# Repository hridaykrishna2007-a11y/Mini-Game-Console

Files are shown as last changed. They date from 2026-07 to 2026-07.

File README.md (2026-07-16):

# Mini-Game-Console
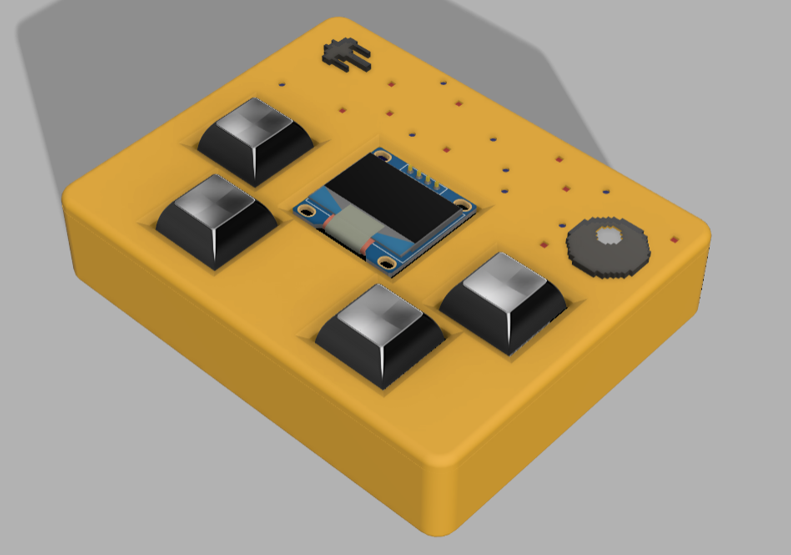
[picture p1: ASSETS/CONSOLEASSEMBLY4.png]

## ***Small handheld game console, it runs on an arduino nano!***
This small DIY console is designed to make teens learn how to build real hardware projects, play games and teach them how to code.  
It runs on an arduino nano and takes power from a usb power source. It has 4 Mechanical CherryMX keyboard switches as the controller buttons. and a 128x64 OLED display!  

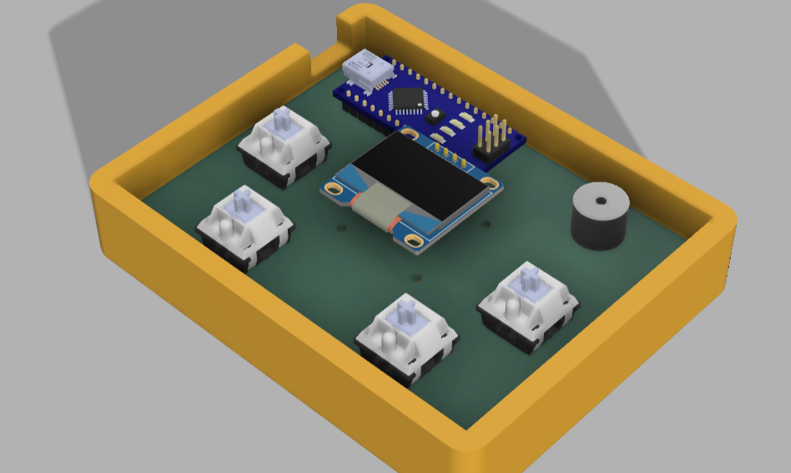
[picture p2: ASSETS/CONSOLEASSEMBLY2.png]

## ***PCB Design & Assembly***
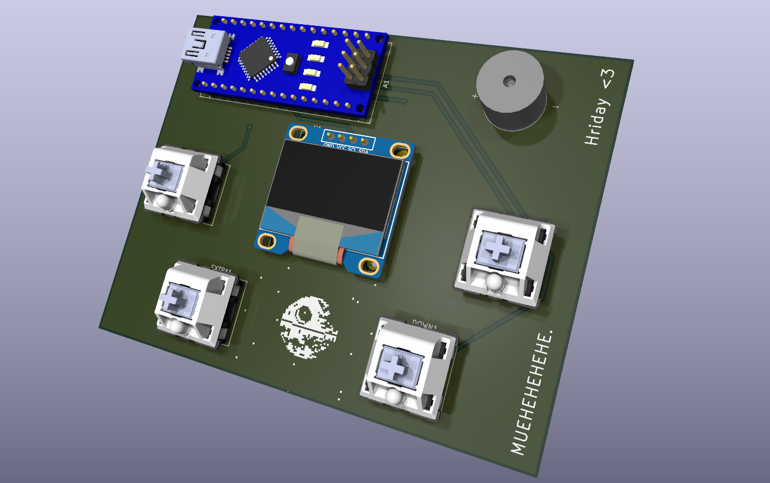
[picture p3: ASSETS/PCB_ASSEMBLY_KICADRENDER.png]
  

This is a 2 layer PCB with dimentions of 99.40x77.02 mm.  

**PCB FILES HERE:** [Link](https://github.com/hridaykrishna2007-a11y/Mini-Game-Console/tree/main/PCB)

## ***Schematics***  
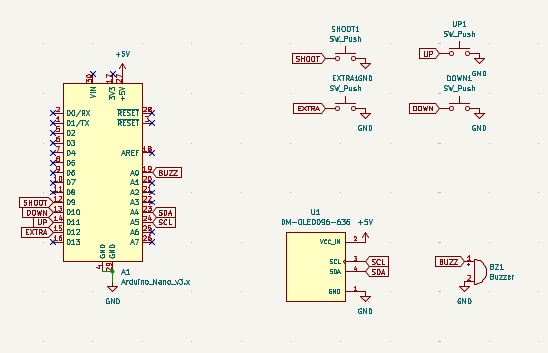
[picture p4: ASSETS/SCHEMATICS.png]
  

## ***PCB Design***
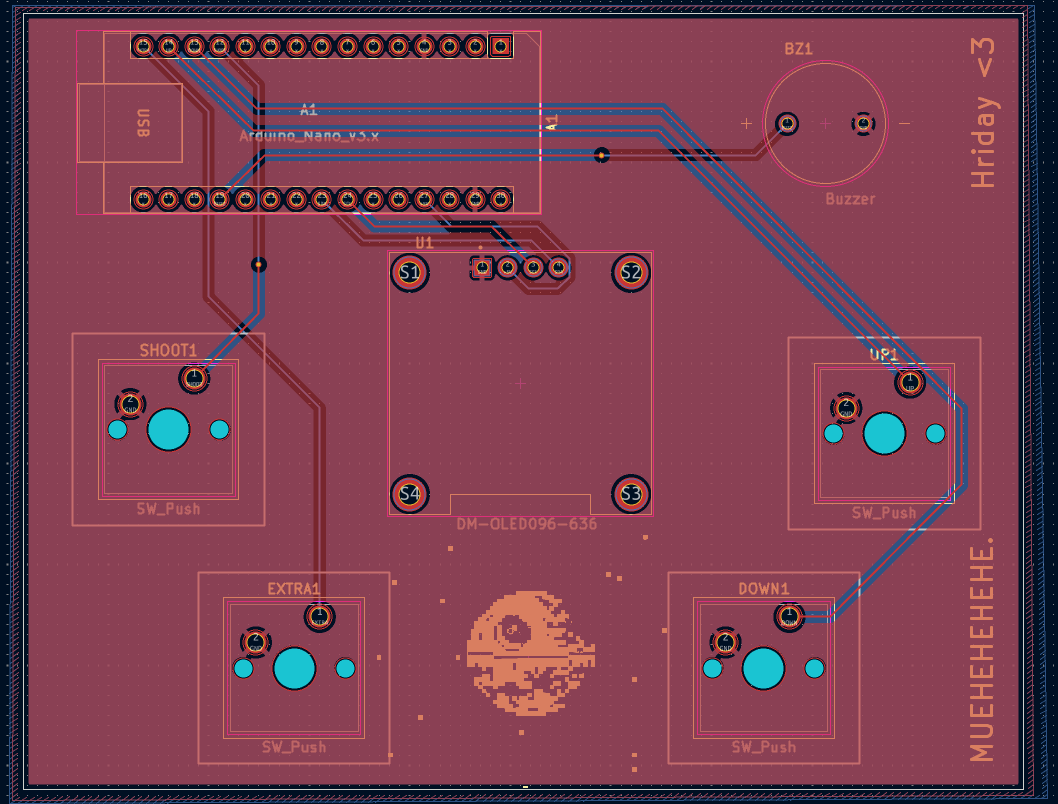
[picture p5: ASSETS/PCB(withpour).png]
  

## Why it was made?
This Project was made for Horizons arcana in singapore ! ( THANK YOU HACK CLUB <3 )

## HOW TO BUILD THIS PROJECT:  
Easy Peasy.
- Order the parts from the BOM and get the case and the keycaps 3d printed and ready.
- Solder the parts on the pcb and keep the orientations in mind (or you are cooked).
- Superglue the case together. (This project is designed keeping portablity and light weight in mind. Hence no screws as it will increase the weight)
- Purchase or 3d print some keycaps (here's one: https://www.printables.com/model/118708-simple-cherry-mx-keycap)
- upload your code (or the sample one in this same repo) using usb cable and arduino ide.
- connec to a power source like a powerbank.
- PLAYYYYYYYY!!!!!!

https://github.com/user-attachments/assets/bd86371d-4319-4f34-b711-88d048939bdb

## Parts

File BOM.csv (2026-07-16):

PRODUCT | DESCRIPTION | QUANTITY | UNIT PRICE | TOTAL COST (INCL. SHIPPING) | LINK
PCB | console pcb | 5 [moq] | 315 | 1861
Arduino nano | Arduino nano microcontroller | 1 | 200 | 200 | https://robocraze.com/products/nano-development-board-compatible-with-arduino
Cable | mini usb cable for the arduino nano | 1 | 39 | 39 | https://robocraze.com/products/mini-usb-cable-0-5-metre-color-may-vary
oled 128x64 | SSD1306 I2C OLED | 1 | 162 | 162 | https://robocraze.com/products/0-96in-oled-display-module-4pin
buzzer | buzzer | 1 | 14 | 14 | https://robocraze.com/products/3-volts-buzzer-small
mechanical switches | swicthes for the keys of the controller | 10 (moq) | 180 | 180 | https://stackskb.com/store/click-inc-hp-switch-pack-of-10-pre-order/
keycaps | keycaps | 4 |  |  | Self Sourced (3D-Printed)
case | case of the pcb | 1 |  |  | Self Sourced (3D-Printed)

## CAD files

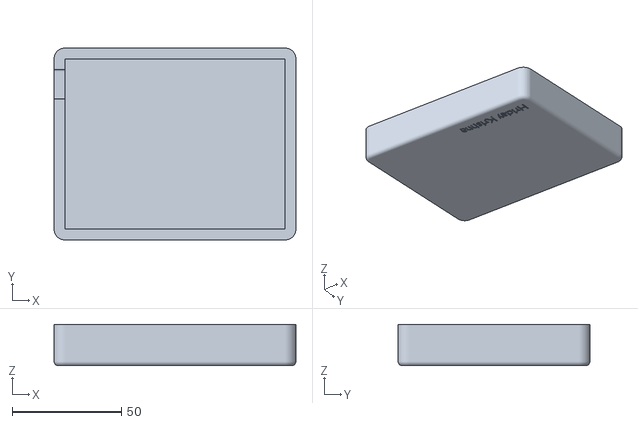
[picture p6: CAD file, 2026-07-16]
PRODUCTION/ENCLOSURE/Case_bottom.stl
111.0 x 88.0 x 19.0

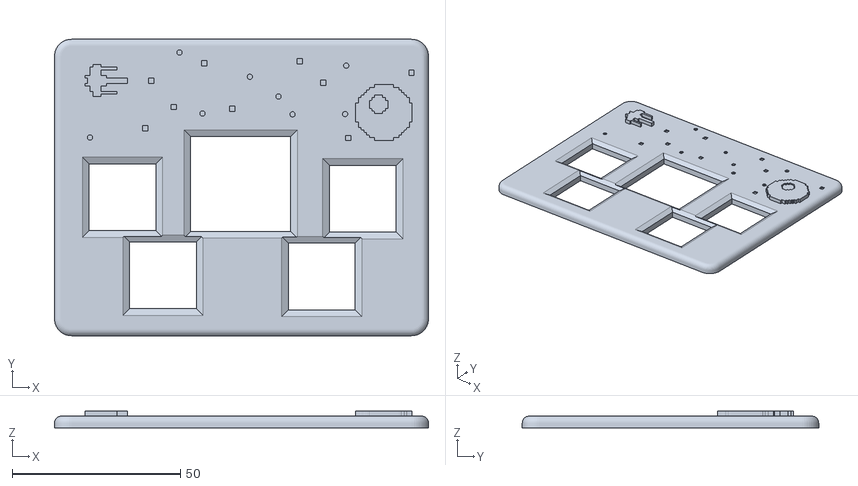
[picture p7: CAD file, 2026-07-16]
PRODUCTION/ENCLOSURE/Case_top.stl
111.0 x 88.0 x 5.00

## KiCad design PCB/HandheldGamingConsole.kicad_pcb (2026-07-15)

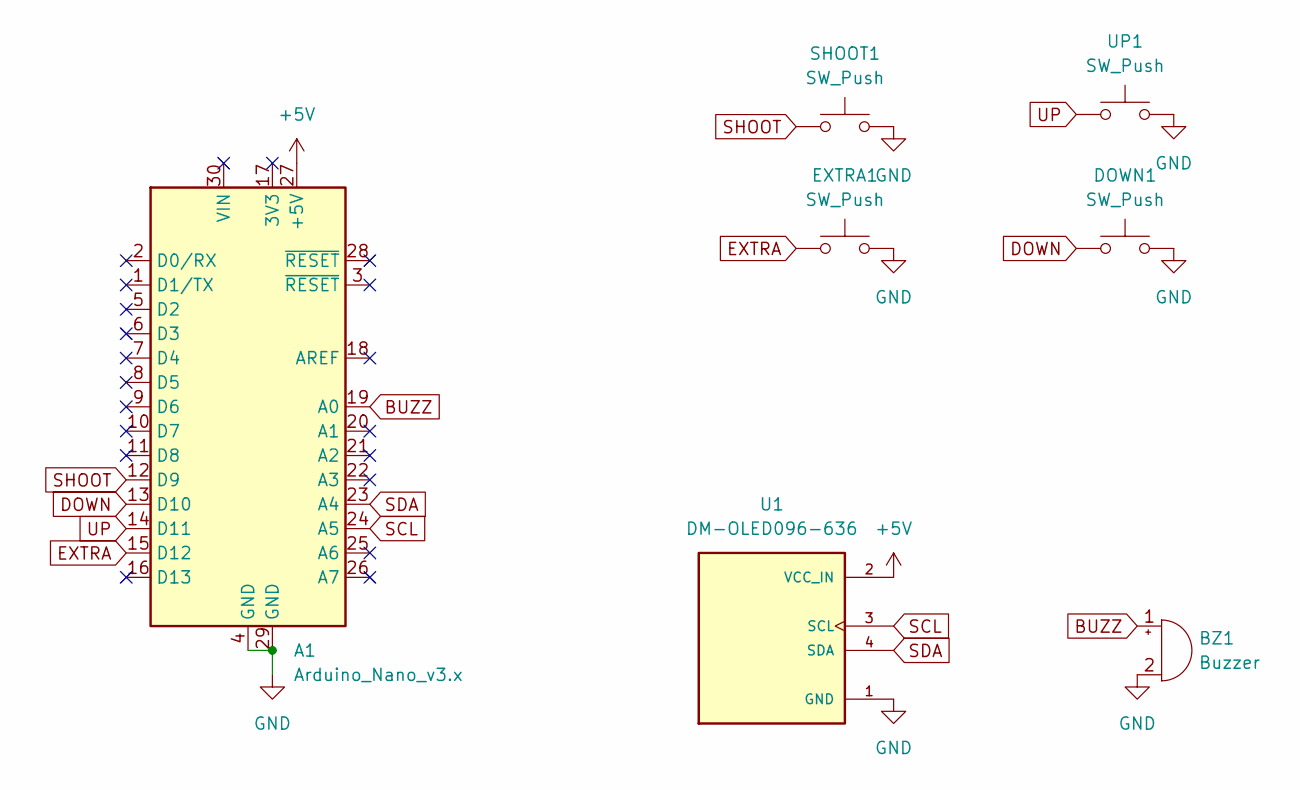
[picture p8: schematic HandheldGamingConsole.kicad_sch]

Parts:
A1: Arduino_Nano_v3.x; Arduino_Nano
BZ1: Buzzer; XDCR_KXG1203C
DOWN1: SW_Push; SW_Cherry_MX_1.00u_PCB
EXTRA1: SW_Push; SW_Cherry_MX_1.00u_PCB
SHOOT1: SW_Push; SW_Cherry_MX_1.00u_PCB
U1: DM-OLED096-636; MODULE_DM-OLED096-636; PARTREV 2018-09-10
UP1: SW_Push; SW_Cherry_MX_1.00u_PCB

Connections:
+5V: A1.27 (+5V), U1.2 (VCC_IN)
BUZZ: A1.19 (A0), BZ1.1 (+)
DOWN: A1.13 (D10), DOWN1.1
EXTRA: A1.15 (D12), EXTRA1.1
GND: A1.4 (GND), A1.29 (GND), BZ1.2 (-), DOWN1.2, EXTRA1.2, SHOOT1.2, U1.1 (GND), UP1.2
SCL: A1.24 (A5), U1.3 (SCL)
SDA: A1.23 (A4), U1.4 (SDA)
SHOOT: A1.12 (D9), SHOOT1.1
UP: A1.14 (D11), UP1.1

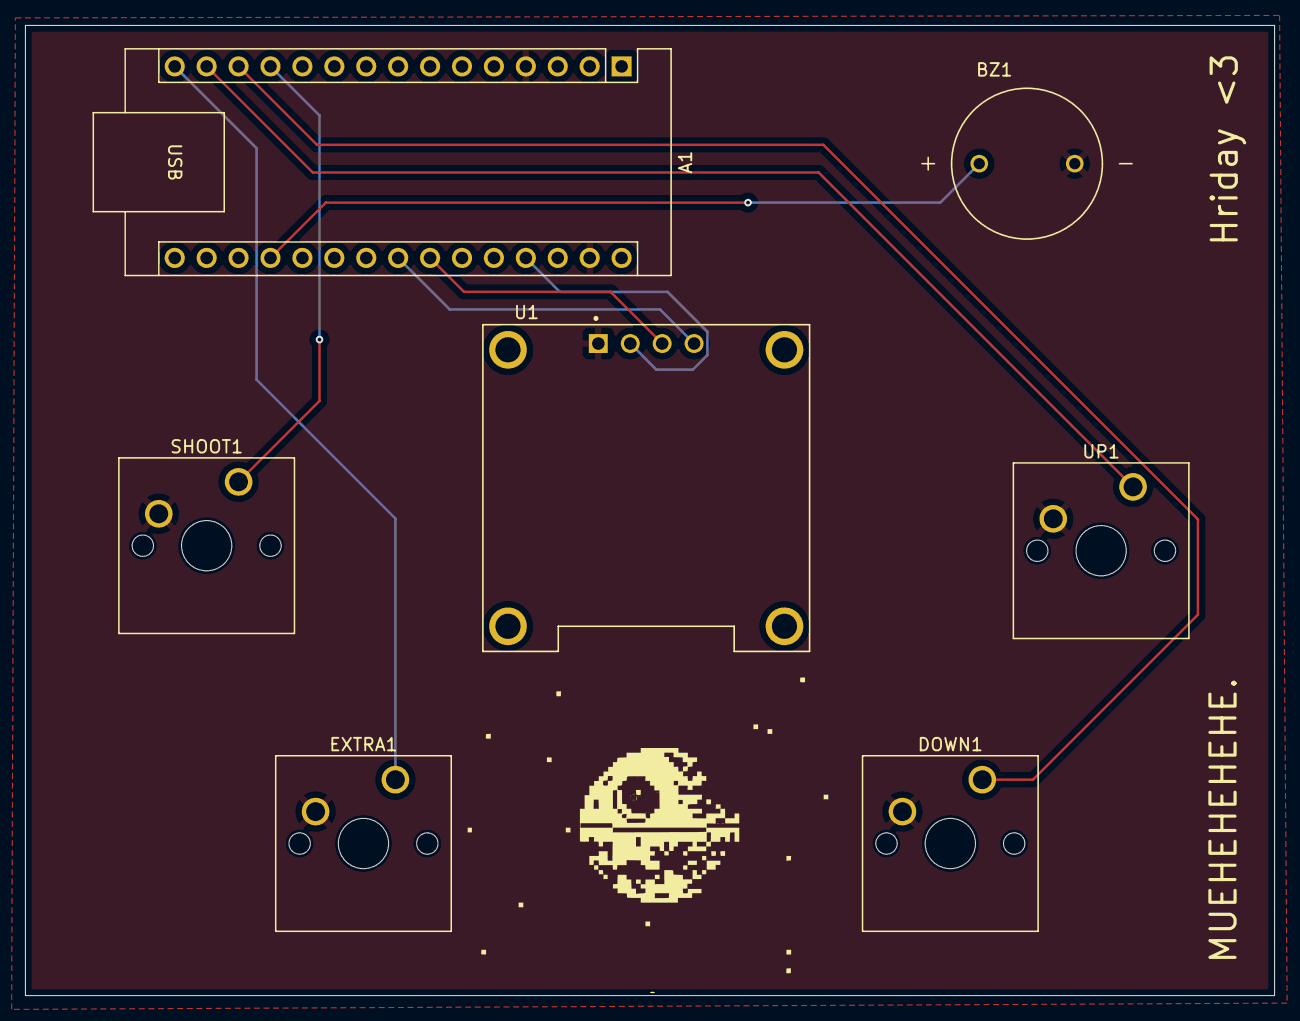
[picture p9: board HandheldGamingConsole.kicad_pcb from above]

Board: 2 copper layers, 99.4 x 77.2 mm, 7 parts (0 on the bottom side), 9 nets.

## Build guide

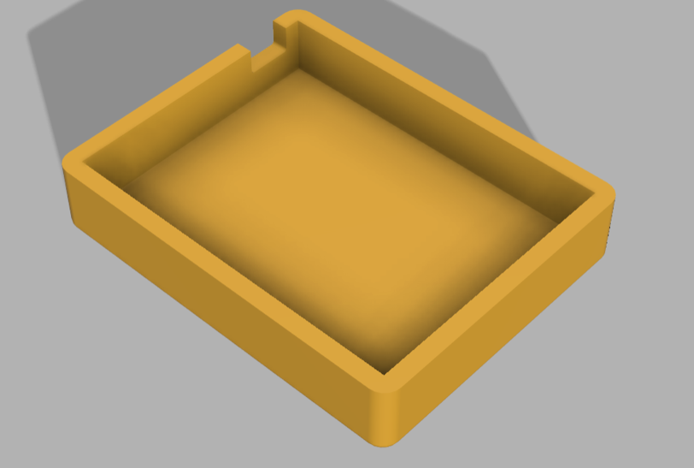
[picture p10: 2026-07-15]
ASSETS/CONSOLEASSEMBLY1.png

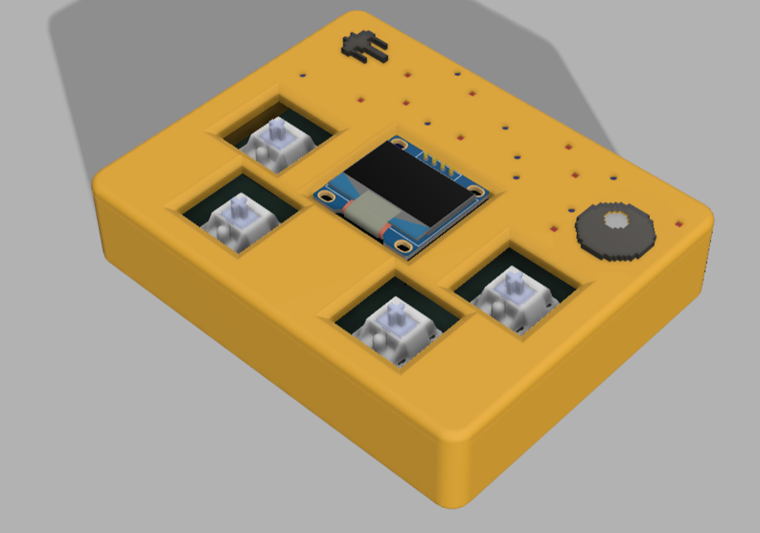
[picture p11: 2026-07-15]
ASSETS/CONSOLEASSEMBLY3.png

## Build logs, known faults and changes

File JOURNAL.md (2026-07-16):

---
title: "Mini Game Console"
author: "@Hriday Krishna"
description: "This is a small handheld game console u can use to play some games! it runs on an arduino nano. it has 3 buttons and a 128x64 display!"
created_at: "2026-07-10"
---
# Mini-Game-Console
## Journal-1: tested the circuit on wokwi and made schematics [13th Jul, 2026; 7:01 pm] [J-1]
- IMP NOTE: I am slow at typing T-T 
- Tested and troubleshooted the circuit and logic on wokwi. due to a breadboard error i made,I got confused lol
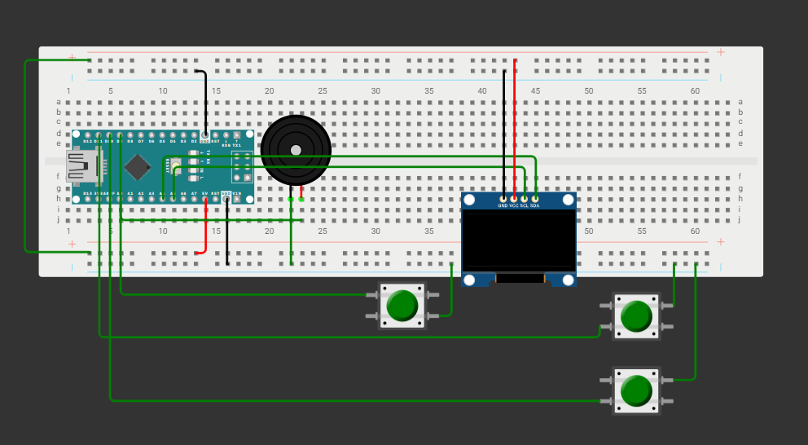
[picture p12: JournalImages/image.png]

- made the schematics on kicad. Added extra control buttons so that the console could be used with manyyy games.
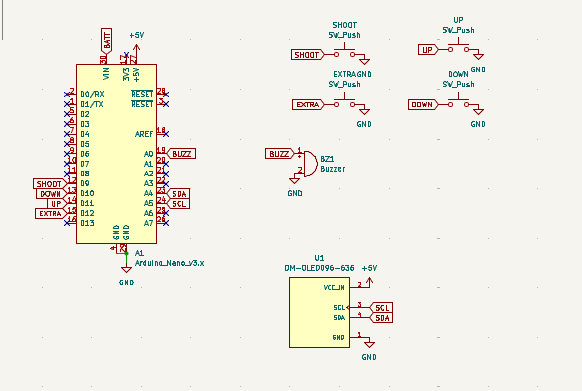
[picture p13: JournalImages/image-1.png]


Recordings:
1. https://lapse.hackclub.com/timelapse/9d2t55453Uiu
2. https://lapse.hackclub.com/timelapse/nDKRG0l3SooJ
3. https://lapse.hackclub.com/timelapse/hTYw8-52Bi8z
4. https://lapse.hackclub.com/timelapse/-t1wMTPBpjFD
Time taken: 191 minutes : 3 hr 11 min

## Journal-2: Finished working on the pcb [14th Jul, 2026; 2:15 pm]
- Downloaded and imported the footprints of the components i am using in the project
- Decided to drop using the battery and use usb power because it got heave and defeated the purpose of this being portable.
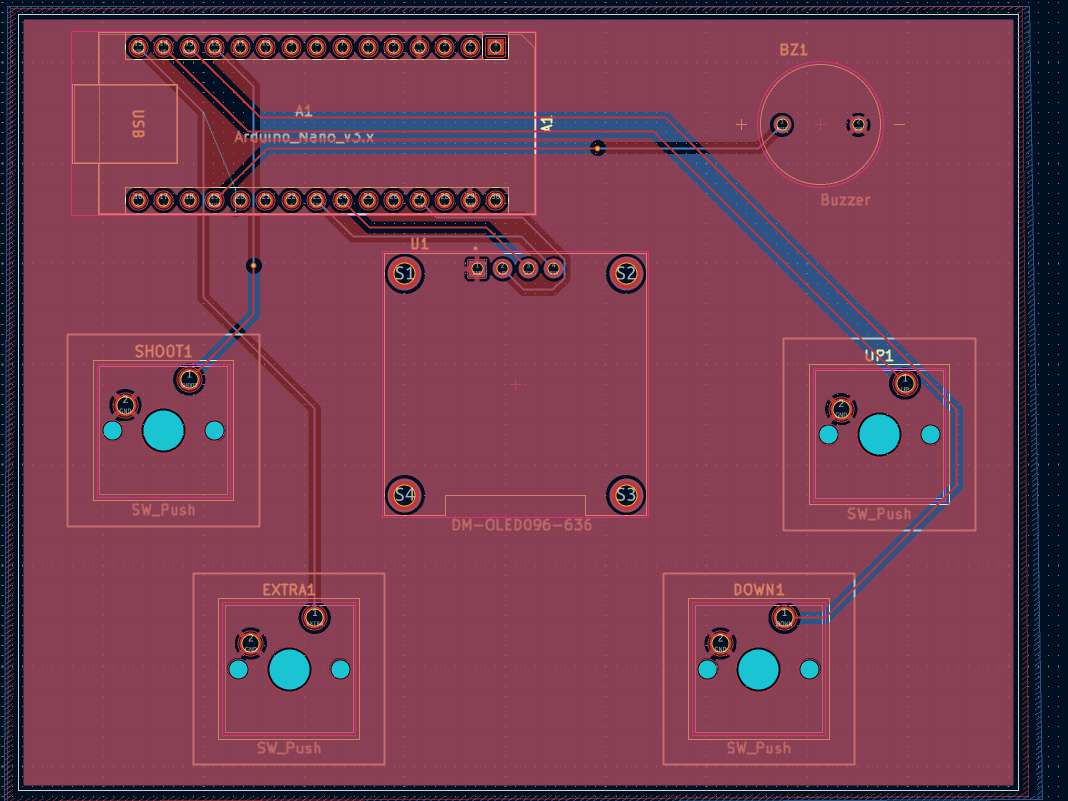
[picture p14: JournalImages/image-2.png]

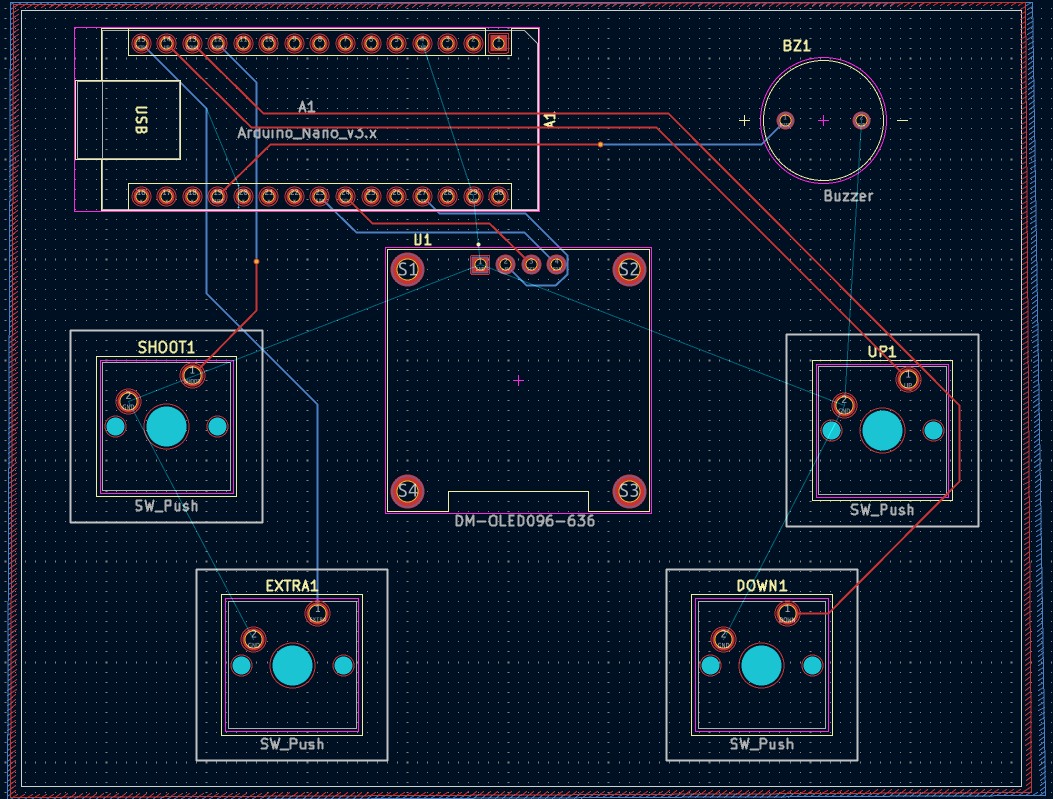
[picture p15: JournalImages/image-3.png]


Recordings:
5. https://lapse.hackclub.com/timelapse/oJeSY94ifWu1
6. https://lapse.hackclub.com/timelapse/bdBB9f8efjW5
Time taken: 85 min : 1 hr 25 min.

## Journal-3: assigned the 3d models and made the case. [15th Jul, 2026; 3:00 pm]
- downloaded the  3d .step model of the components and assigned them to the respective footprints.
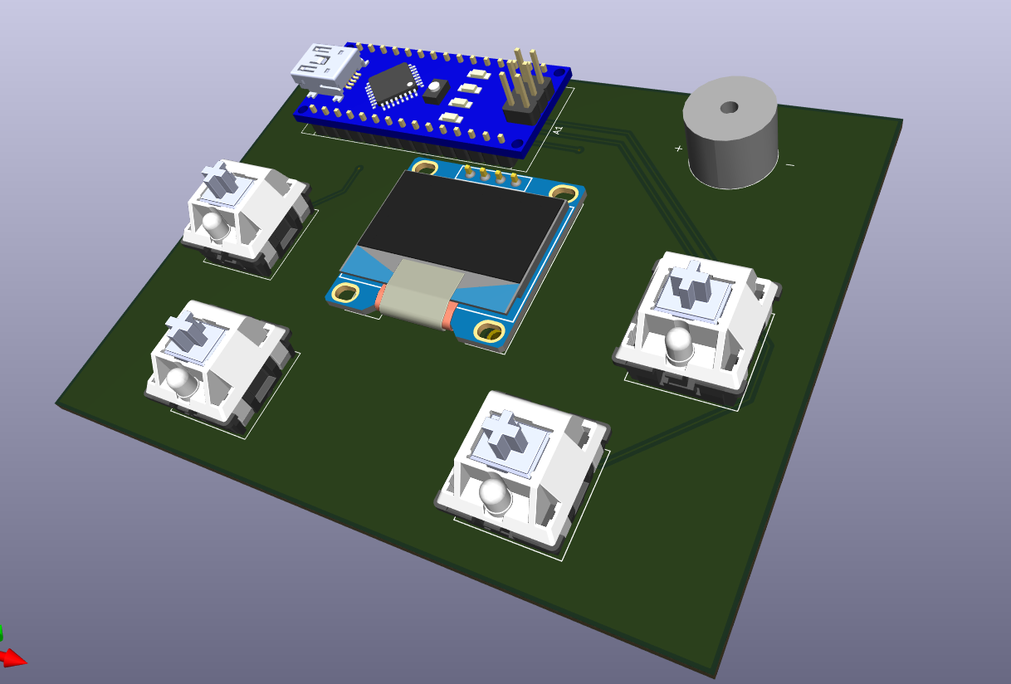
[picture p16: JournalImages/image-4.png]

- Learnt and exported the 3d model of the pcb assembly to fusion to build a case around it.
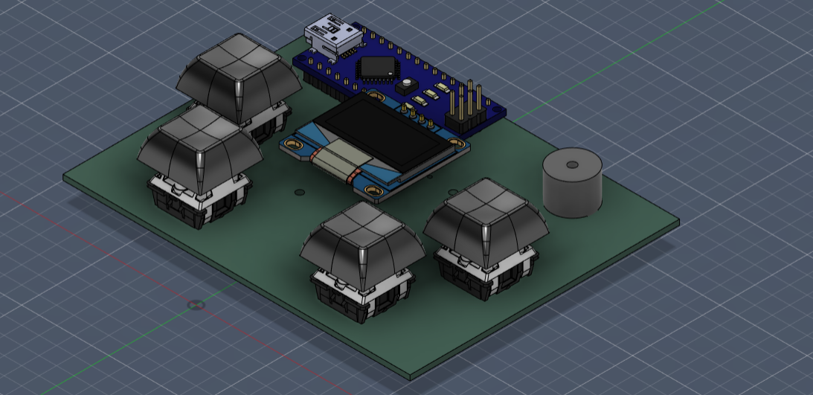
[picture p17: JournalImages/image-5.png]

- designed the case around the pcb assembly
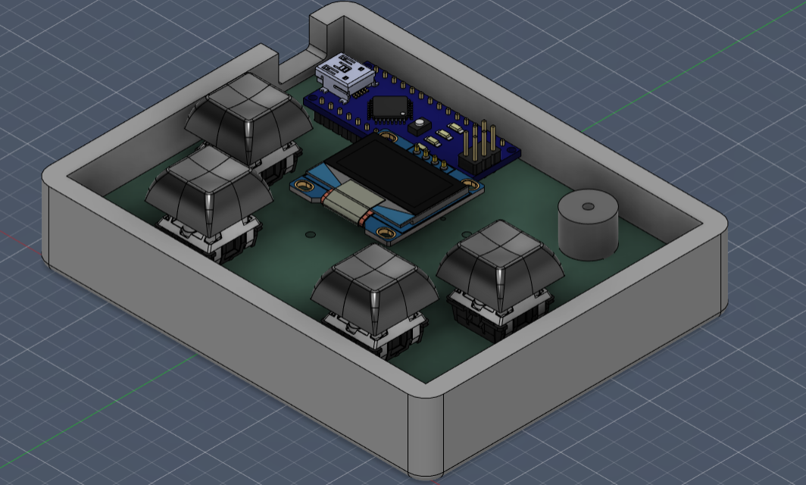
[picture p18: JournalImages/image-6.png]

- made some art on the case to make it look special <3
- now assigning colours to it! [learnt how to do that on YT]
- made a few .svg files to help me assist in extruding the deathstar and the X-Wing.
- added som squares and circles as the projectiles shot by the spacecrafts.
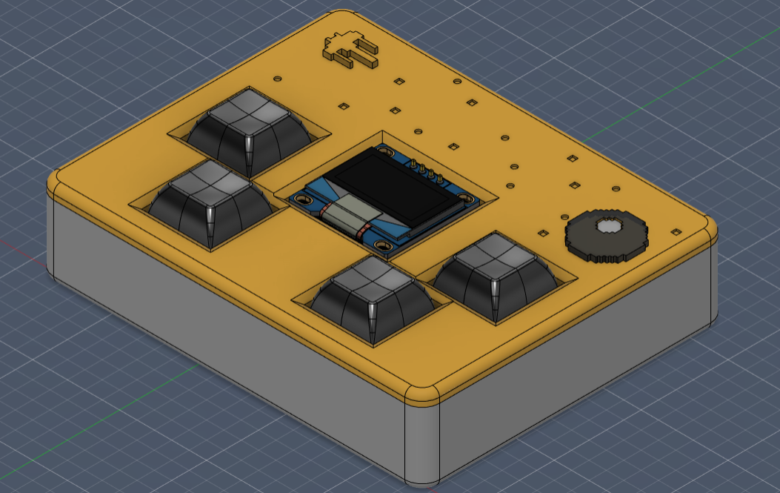
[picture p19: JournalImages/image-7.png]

- I still have some colour assigning to do lol.

Timelapses:
7. https://lapse.hackclub.com/timelapse/M0RD4-lXABkA
8. https://lapse.hackclub.com/timelapse/JNOY_ep9VuGy
9. https://lapse.hackclub.com/timelapse/km-6RsCr_r-d
10. https://lapse.hackclub.com/timelapse/JjaPQTsMu-mx
11. https://lapse.hackclub.com/timelapse/WApxHjhJyl0f
Total Time taken: 134 min; 2 hr 14 min
total time at hackatime atp: 7 hr 40 min 

## Journal-4: Art, Pcb final Iterations, Documentation [15th Jul, 2026; 9:15 pm]
- completed the art. thought that id use some realizm in the coulour of the laser projectiles used in the deathstar and the X-wing but it didnt look good so i let it be blue and red.
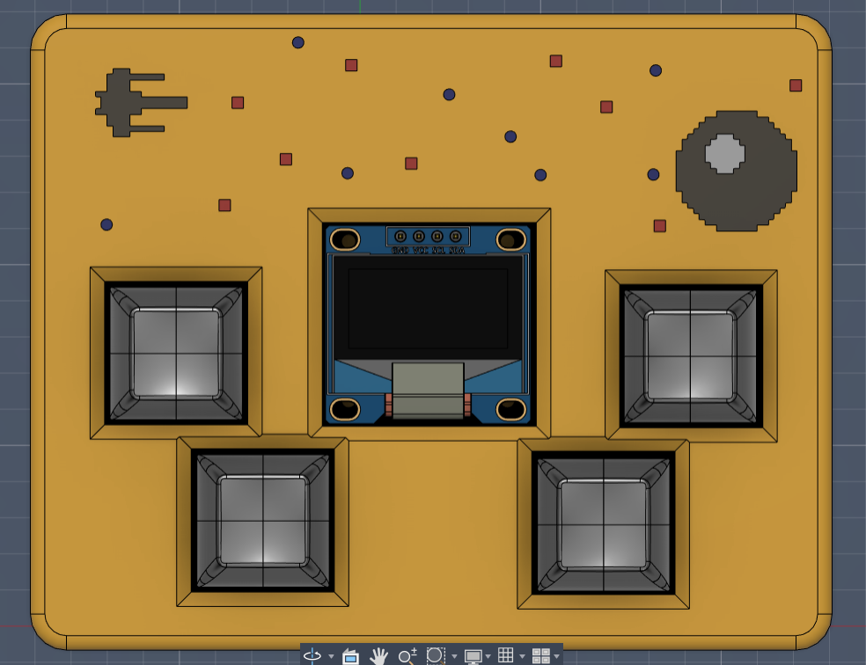
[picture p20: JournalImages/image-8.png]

- took screenshots for progress and documentatioan
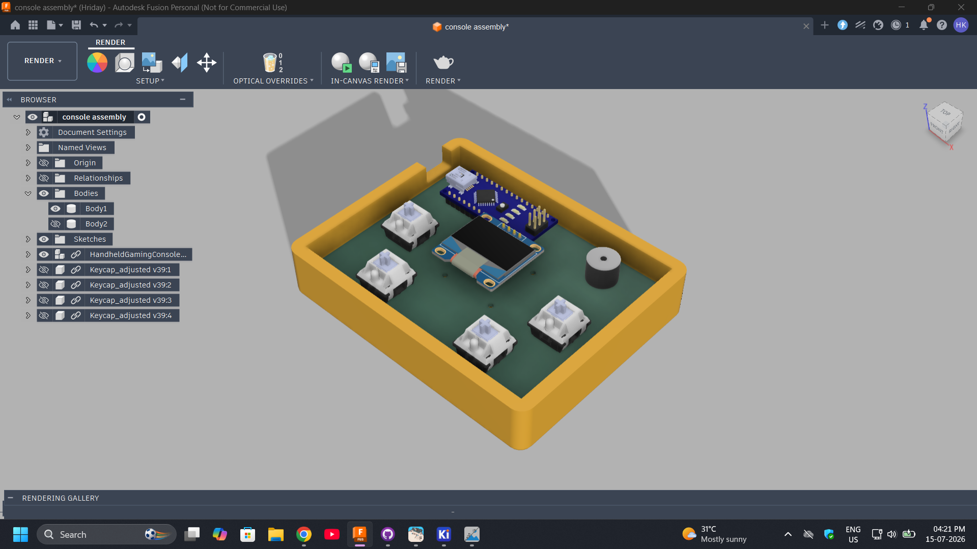
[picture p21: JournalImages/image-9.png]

- added some silkscreen art on the pcb cuz i thought it looked a little boring.

- used the interference tool to check for any interference and to see id everything fits well together.
- added my name on the case.

Timelapses: 
12. https://lapse.hackclub.com/timelapse/1AsCNXXIjcNe
13. https://lapse.hackclub.com/timelapse/r8QRYEGJ9JFt
Tima taken: 55 min
total time at hackatime atp: 9hr 24s

## Journal-5: file uploads and README.md 
- finally got my repo filled with all the files  
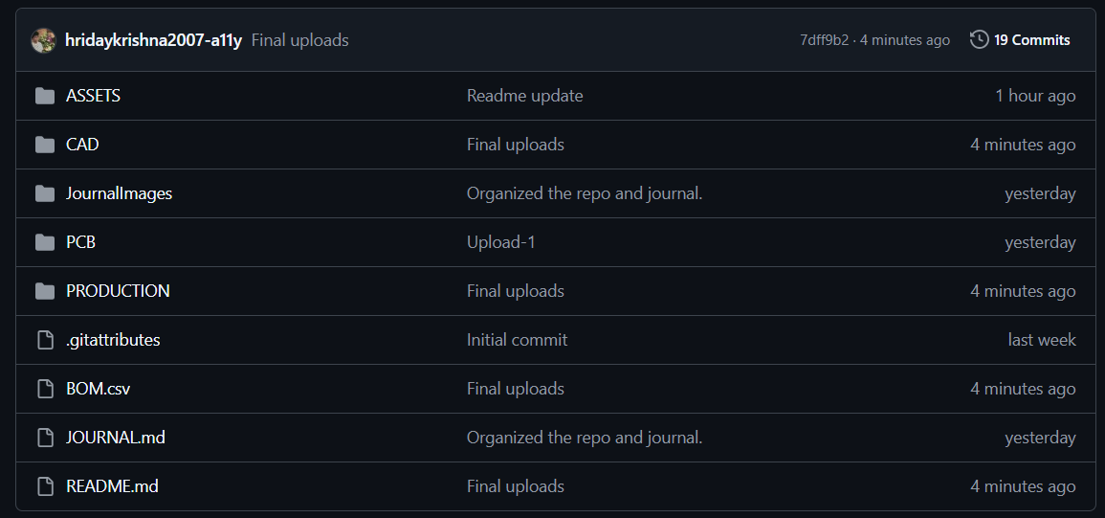
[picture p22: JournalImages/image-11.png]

- i faced some issues. images on readme werent visible. aparantly i used '\' instead of '/' in the file names loll.  

Timelapses:  
14. https://lapse.hackclub.com/timelapse/k9l5WchVmxKt
15. https://lapse.hackclub.com/timelapse/VjFZTxw4sLwA
Time: 50 mins
total time at hackatime atp: 11 hr 22 min

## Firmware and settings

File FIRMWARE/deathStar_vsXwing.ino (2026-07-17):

/*
 * Arduino Star Wars Game "Death Star vs Xwing"
 * Code modified and tested by Max Imagination
 * Instagram: @max.imagination
 * YouTube: Max Imagination
 * https://wokwi.com/projects/469180920695344129
 * Credits to @volosprojects on YouTube for sharing the code
 */

#include <SPI.h>
#include <Wire.h>
#include <Adafruit_GFX.h>
#include <Adafruit_SSD1306.h> 
#include <Fonts/FreeSans9pt7b.h>
//#include <Fonts/FreeSans12pt7b.h>

#define OLED_RESET 4
Adafruit_SSD1306 display(128, 64, &Wire, OLED_RESET);

const int c = 261;
const int d = 294;
const int e = 329;
const int f = 349;
const int g = 391;
const int gS = 415;
const int a = 440;
const int aS = 455;
const int b = 466;
const int cH = 523;
const int cSH = 554;
const int dH = 587;
const int dSH = 622;
const int eH = 659;
const int fH = 698;
const int fSH = 740;
const int gH = 784;
const int gSH = 830;
const int aH = 880;

const unsigned char PROGMEM dioda16 [] = {

0x00, 0x00, 0x00, 0x00, 0x1C, 0x00, 0x3F, 0xF0, 0x3C, 0x00, 0x3C, 0x00, 0xFF, 0x00, 0x7F, 0xFF,
0x7F, 0xFF, 0xFF, 0x00, 0x3C, 0x00, 0x3C, 0x00, 0x1F, 0xF0, 0x1C, 0x00, 0x00, 0x00, 0x00, 0x00

};

const unsigned char PROGMEM storm [] = {
0x00, 0x00, 0x00, 0x00, 0x00, 0x00, 0x00, 0x00, 0x00, 0x00, 0x00, 0x00, 0x00, 0x00, 0x00, 0x00,
0x00, 0x00, 0x00, 0x00, 0x7F, 0xFE, 0x00, 0x00, 0x00, 0x07, 0x80, 0x01, 0xE0, 0x00, 0x00, 0x0C,
0x00, 0x00, 0x20, 0x00, 0x00, 0x18, 0x00, 0x00, 0x18, 0x00, 0x00, 0x30, 0x00, 0x00, 0x04, 0x00,
0x00, 0x20, 0x00, 0x00, 0x04, 0x00, 0x00, 0x20, 0x00, 0x00, 0x04, 0x00, 0x00, 0x60, 0x00, 0x00,
0x02, 0x00, 0x00, 0x40, 0x00, 0x00, 0x02, 0x00, 0x00, 0x40, 0x00, 0x00, 0x01, 0x00, 0x00, 0x40,
0x00, 0x00, 0x01, 0x00, 0x00, 0x40, 0x00, 0x00, 0x01, 0x00, 0x00, 0x7F, 0xE0, 0x00, 0x01, 0x00,
0x00, 0x7F, 0xFF, 0xFF, 0xFF, 0x00, 0x00, 0x7F, 0xFF, 0xFF, 0xFF, 0x00, 0x00, 0xD7, 0xFF, 0xFF,
0xE1, 0x00, 0x01, 0xBF, 0xFC, 0x1F, 0xFA, 0x80, 0x01, 0xBF, 0xF1, 0xCF, 0xFA, 0x80, 0x01, 0x3F,
0xC2, 0x37, 0xF7, 0x80, 0x01, 0xEF, 0x9C, 0x01, 0xE7, 0xC0, 0x01, 0xE0, 0x70, 0x06, 0x06, 0x80,
0x01, 0xE0, 0xC0, 0x03, 0x06, 0x80, 0x01, 0xFF, 0x80, 0x01, 0xFF, 0x80, 0x01, 0xF8, 0x00, 0x00,
0x1D, 0xC0, 0x03, 0x70, 0x00, 0x80, 0x0C, 0x60, 0x05, 0xB0, 0x07, 0xF0, 0x08, 0x90, 0x09, 0x10,
0x1F, 0xF8, 0x09, 0xD0, 0x0B, 0x90, 0x1F, 0x7C, 0x03, 0xF0, 0x0F, 0xC0, 0xFC, 0x0F, 0x07, 0x90,
0x0D, 0x43, 0xC0, 0x03, 0x07, 0x90, 0x05, 0x64, 0x00, 0x00, 0xCF, 0x10, 0x07, 0xFC, 0x00, 0x00,
0x26, 0x10, 0x01, 0x80, 0x00, 0x00, 0x10, 0x20, 0x01, 0x00, 0x00, 0x00, 0x0E, 0x40, 0x01, 0x80,
0x07, 0xF0, 0x01, 0x80, 0x00, 0x80, 0x07, 0xC8, 0x00, 0x80, 0x00, 0x80, 0x0B, 0xE8, 0x00, 0x80,
0x00, 0x87, 0x97, 0xE9, 0xE0, 0x80, 0x00, 0x87, 0xDF, 0xEF, 0xA0, 0x80, 0x00, 0x4B, 0xFF, 0xFF,
0xA0, 0x80, 0x00, 0x6B, 0xDF, 0xFB, 0xA3, 0x00, 0x00, 0x24, 0x97, 0xE8, 0x24, 0x00, 0x00, 0x1E,
0x1F, 0xC0, 0x2C, 0x00, 0x00, 0x07, 0xF8, 0x1F, 0xF0, 0x00, 0x00, 0x00, 0x0F, 0xF8, 0x00, 0x00
};



void setup()   {                
 

 pinMode(9,INPUT_PULLUP); //define your Shoot button
 pinMode(11,INPUT_PULLUP); //define your "Move up" button
 pinMode(10,INPUT_PULLUP); //define your "Move down" button 
 pinMode(A0, OUTPUT); //define your Buzzer's signal pin
  display.begin(SSD1306_SWITCHCAPVCC, 0x3C);  
  display.display();
  display.clearDisplay();
display.setTextSize(0);
   display.drawBitmap(6, 11,storm, 48,48, 1);
    display.setFont(&FreeSans9pt7b);
  display.setTextColor(WHITE);
    display.setCursor(65,14);
  display.println("xWing");
   display.setFont();
  display.setCursor(65,17);
  display.setTextSize(0);
  display.println("vs");
  display.setCursor(0,0);
  float voltaza=readVcc()/1000;
  display.println(voltaza);;
  display.setFont(&FreeSans9pt7b);
  display.setCursor(65,39);
  display.println("Death");
  display.setFont();
  display.setCursor(65,42);
  display.println("star ");
  display.setTextSize(0);
  
  display.setCursor(65,55);
 
  display.println("by Danko");
  
    display.setCursor(65,20);

   display.display();
   
 

display.setFont(); 
 beep(a, 500);
  beep(a, 500);    
  beep(a, 500);
  beep(f, 350);
  beep(cH, 150);  
  beep(a, 500);
  beep(f, 350);
  beep(cH, 150);
  beep(a, 650);
 
  delay(500);
 
 
 
  delay(500);
}
int metx=0;
int mety=0;
int postoji=0;
int nep=8;
int smjer=0;
int go=0;
int rx=95;
int ry=0;
int rx2=95;
int ry2=0;
int rx3=95;
int ry3=0;
int bodovi=0;

int brzina=3; //speed of bullet
int bkugle=1;
int najmanja=600;
int najveca=1200;
int promjer=10;

int rx4=95;
int ry4=0;
int zivoti=5;
int poc=0;
int ispaljeno=0;
int nivo=1;
int centar=95;
unsigned long pocetno=0;
unsigned long odabrano=0;
unsigned long trenutno=0;
unsigned long nivovrije=0;
int poz=30;
void loop() {

  if(go==0){
  display.clearDisplay();

display.drawPixel(50,30,1);
display.drawPixel(30,17,1);
display.drawPixel(60,18,1);
display.drawPixel(55,16,1);
display.drawPixel(25,43,1);
 display.drawPixel(100,43,1); 
display.drawPixel(117,52,1);
display.drawPixel(14,49,1);
display.drawPixel(24,24,1);
display.drawPixel(78,36,1);
display.drawPixel(80,57,1);
display.drawPixel(107,11,1);
display.drawPixel(150,11,1);
display.drawPixel(5,5,1);
display.drawPixel(8,7,1);
display.drawPixel(70,12,1);
display.drawPixel(10,56,1);
display.drawPixel(70,25,1);


  
  if(poc==0){
  pocetno=millis();
  odabrano= random(400,1200);
  poc=1;
  }
 trenutno=millis();


//nivoi

if((trenutno-nivovrije)>50000)
{
  nivovrije=trenutno;
  nivo=nivo+1;

 brzina=brzina+1; //brizna neprijateljevog metka
 if ( nivo % 2 == 0 )
    {
       bkugle=bkugle+1;
       promjer=promjer-1;
    }
najmanja=najmanja-50;
najveca=najveca-50;

  }



 if((odabrano+pocetno)<trenutno)
  {
    poc=0;
   ispaljeno=ispaljeno+1;
   if(ispaljeno==1)
   {rx=95;
    ry=nep;}
     if(ispaljeno==2){
      rx2=95;
      ry2=nep;}
      if(ispaljeno==3)
      {
        rx3=95;
          ry3=nep;
      }
  
      
     if(ispaljeno==4){
      rx4=95;
      ry4=nep;
     
     }
     
    
      
   }

  
    if(ispaljeno>0)
    {
    display.drawCircle(rx,ry,2,1);
    rx=rx-brzina;}

    if(ispaljeno>1)
    {
    display.drawCircle(rx2,ry2,1,1);
    rx2=rx2-brzina;}

     if(ispaljeno>2)
    {
    display.drawCircle(rx3,ry3,4,1);
    rx3=rx3-brzina;}

     if(ispaljeno>3)
    {
    display.drawCircle(rx4,ry4,2,1);
    rx4=rx4-brzina;}

 if(digitalRead(11)==0 && poz>=2){
 poz=poz-2;}

  if(digitalRead(10)==0&& poz<=46){
 poz=poz+2;}
  

   if(digitalRead(9)==0 && postoji==0)
  {
    postoji=1;
    metx=6;
    mety=poz+8;
    tone(A0,1200,20);
  
    
    }
   if(postoji==1)

    {
    metx=metx+8 ;
    
    display.drawLine(metx,mety,metx+4,mety,1);
    }
   
   display.drawBitmap(4, poz,dioda16, 16,16, 1);
   display.fillCircle(centar,nep,promjer,1);
   display.fillCircle(centar+2,nep+3,promjer/3,0);

 display.setTextSize(1);
  display.setTextColor(WHITE);
  display.setCursor(33,57);
  display.println("score:");
    display.setCursor(68,57);
  display.println(bodovi);

   display.setCursor(33,0);
  display.println("lives:");
    display.setCursor(68,0);
  display.println(zivoti);
   
   display.setCursor(110,0);
  display.println("L:");

  display.setCursor(122,0);
  display.println(nivo);

  display.setCursor(108,57);
  display.println(trenutno/1000);
   display.display();

   if(metx>128)postoji=0;
  
 
  
   if(smjer==0){
   nep=nep+bkugle;}
   else
   {nep=nep-bkugle;}

   if(nep>=(64-promjer))
   smjer=1;
   if(nep<=promjer)
   smjer=0;

   if(mety>=nep-promjer && mety<=nep+promjer)
   if(metx>(centar-promjer)&&metx<(centar+promjer))
   {
   metx=-20;
   tone(A0,500,20);
   bodovi=bodovi+1;
   postoji=0;
   }

int pozicija=poz+8;
     if(ry>=pozicija-8 && ry<=pozicija+8)
   if(rx<12&&rx>4)
   {
   rx=95;
   ry=-50;
   tone(A0,100,100);
 zivoti=zivoti-1;
   }

        if(ry2>=pozicija-8 && ry2<=pozicija+8)
   if(rx2<12&&rx2>4)
   {
   rx2=-50;
   ry2=-50;
   tone(A0,100,100);
 zivoti=zivoti-1;
   }

      if(ry3>=pozicija-8 && ry3<=pozicija+8)
   if(rx3<12&&rx3>4)
   {
   rx3=-50;
   ry3=-50;
   tone(A0,100,100);
 zivoti=zivoti-1;
   }

      if(ry4>=pozicija-8 && ry4<=pozicija+8)
   if(rx4<12&&rx4>4)
   {
   rx4=200;
   ry4=-50;
   ispaljeno=0;
   tone(A0,100,100);
 zivoti=zivoti-1;
   }
 
if(rx4<1){
   ispaljeno=0;
   rx4=200;}

   if(zivoti==0)
   go=1;
  }

  if(go==1)
  {
    if(zivoti==0){
     tone(A0,200,300);
     delay(300);
      tone(A0,250,200);
      delay(200);
       tone(A0,300,300);
       delay(300);
       zivoti=5;
    }
   display.clearDisplay();
   display.setFont();  
 display.setTextSize(2);
  display.setTextColor(WHITE);
    display.setCursor(7,10);
  display.println("GAME OVER!");
   display.setTextSize(1);
  display.setCursor(7,30);
   display.println("score:");
    display.setCursor(44,30);
    display.println(bodovi);
    display.setCursor(7,40);
    display.println("level:");
     display.setCursor(44,40);
     display.println(nivo);
     display.setCursor(7,50);
     display.println("time(s):");
       display.setCursor(60,50);
       
       display.println(trenutno/1000);
  display.display();

    if(digitalRead(9)==0)
    {
       tone(A0,280,300);
     delay(300);
      tone(A0,250,200);
      delay(200);
       tone(A0,370,300);
       delay(300);
      ponovo();
    }
    }
}

void ponovo()
{
 metx=0;
 mety=0;
postoji=0;
 nep=8;
 smjer=0;
 go=0;
 rx=95;
 ry=0;
 rx2=95;
 ry2=0;
rx3=95;
ry3=0;
bodovi=0;

 brzina=3; //brizna neprijateljevog metka
bkugle=1;
 najmanja=600;
 najveca=1200;
 promjer=12;

 rx4=95;
ry4=0;
zivoti=5;
poc=0;
 ispaljeno=0;
nivo=1;
 pocetno=0;
 odabrano=0;
 trenutno=0;
nivovrije=0;
  
  
  
  
  }

long readVcc() {
  // Read 1.1V reference against AVcc
  // set the reference to Vcc and the measurement to the internal 1.1V reference
  #if defined(__AVR_ATmega32U4__) || defined(__AVR_ATmega1280__) || defined(__AVR_ATmega2560__)
    ADMUX = _BV(REFS0) | _BV(MUX4) | _BV(MUX3) | _BV(MUX2) | _BV(MUX1);
  #elif defined (__AVR_ATtiny24__) || defined(__AVR_ATtiny44__) || defined(__AVR_ATtiny84__)
    ADMUX = _BV(MUX5) | _BV(MUX0);
  #elif defined (__AVR_ATtiny25__) || defined(__AVR_ATtiny45__) || defined(__AVR_ATtiny85__)
    ADMUX = _BV(MUX3) | _BV(MUX2);
  #else
    ADMUX = _BV(REFS0) | _BV(MUX3) | _BV(MUX2) | _BV(MUX1);
  #endif  

  delay(2); // Wait for Vref to settle
  ADCSRA |= _BV(ADSC); // Start conversion
  while (bit_is_set(ADCSRA,ADSC)); // measuring

  uint8_t low  = ADCL; // must read ADCL first - it then locks ADCH  
  uint8_t high = ADCH; // unlocks both

  long result = (high<<8) | low;

  result = 1125300L / result; // Calculate Vcc (in mV); 1125300 = 1.1*1023*1000
  return result; // Vcc in millivolts
}


void beep(int note, int duration)
{
  //Play tone on buzzerPin
  tone(A0, note, duration);
 

  
    delay(duration);
    


  noTone(A0);
 
  delay(50);
 
 
}
